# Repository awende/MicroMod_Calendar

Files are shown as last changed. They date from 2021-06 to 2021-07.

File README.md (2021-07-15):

# MicroMod Calendar

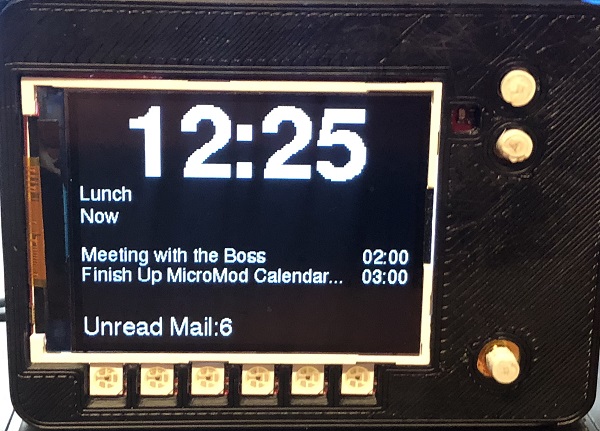
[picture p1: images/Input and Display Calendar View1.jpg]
MicroMod Input and Display Calendar Default View


The MicroMod Calendar uses the SparkFun Input and Display MicroMod Carrier board, paired with the SparkFun ESP32 MicroMod Processor board to show the current time, display next and upcoming meetings, and provide visual alerts using the on-board LEDs. The 5-way switch changes the backlight level, screen orientation, and a secondary view, which provides a little more space between your next meeting and future meetings.

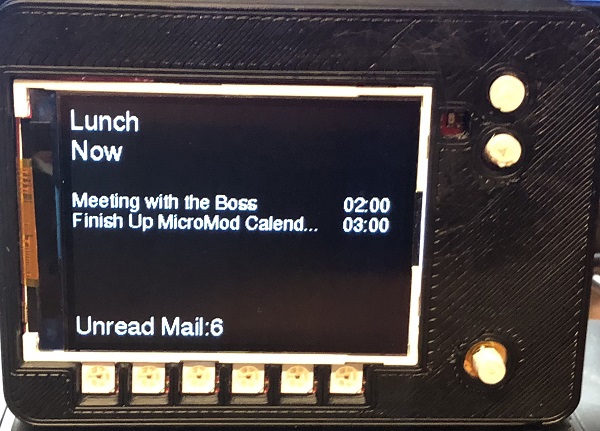
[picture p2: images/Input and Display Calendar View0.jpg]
MicroMod Input and Display Calendar Alternate View


To get this project working, there are two sets of code needed. The first is a script which is added to your Google account, and creates a file which pulls in the meetings from your calendar, and checks to see how many unread emails there are. The second runs on the ESP32, to connect to the Internet to read the data in, and get the current time which can automatically adjust for Dalight Savings based on the the timezone information provided.

Repository Contents
-------------------
* **/Case Files** - .stl files for the case, along with button caps
* **/Firmware** - Arduino code for the ESP32 Micromod, along with the script that needs to be connected to your Google account.

Hardware Used
-------------------
* [SparkFun ESP32 MicroMod Processor Board](https://www.sparkfun.com/products/16781)
* [SparkFun MicroMod Input and Display Carrier Board](https://www.sparkfun.com/products/16985)

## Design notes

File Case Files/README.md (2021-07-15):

This folder contains the 3D models used for the MicroMod Calendar case. The top of the case provides recesses for the switches' housing, and top mounted parts, along with cutouts for the USB-C connector, LCD, LEDs, and buttons. The bottom case has a cutout for the USB-C connector and standoff holes for 4-40 hardware. Hardware isn't needed though as the fit for the Input and Display board is nicely sandwiched between the top and bottom case to hold it in place.

With a little pressure, the 5-way switch cap is held on securely, but round actuators for the button switch caps were a bit tricky to fit correctly. In my prints the recess for the button switches were a bit too tight and I had to hold them with pliers to drill to the correct diameter. The button switch actuators are 0.080" in diamter, and a 0.076" drill provided a good snug fit.

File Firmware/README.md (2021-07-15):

# MicroMod Calendar Firmware

To display your calendar on the SparkFun Input and Display Carrier board, you will need the firmware for the ESP32, along with a script that will arregrate the data from your Google account to a single file. The ESP32 then reads the data and parses it to show on the display. Each peice of firmware goes into more deail below.

## Google Apps Script

There are a few items that the ESP32 needs to access from your Google account:

* Total number of unread emails in your Inbox
* Total number of meetings for the current day
* Name, start time, and end time of each meeting
* Total number of meetings for the next day
* Name, state time, and end time of your first meeting for the next day

In order of the ESP32 to read this information, we'll need to add the script from the CalendarEvents.gs file. To add the script, head over to https://script.google.com and click on new project.

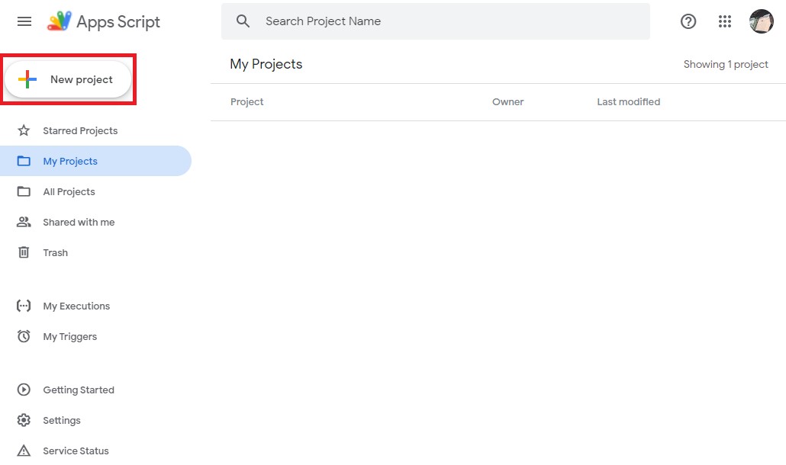
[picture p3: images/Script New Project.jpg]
New Project


From there, add a name for the project. I just called mine "CalendarEvents". Now we can add the code from CalendarEvents.gs file by pasting it into the script editor. Find the variable `_calendarName`, and inside the quotes, add the name of your calendar to add, e.g. 'Work', or your email address. We can test to make sure everything is working by pressing save and then pressing the run button.

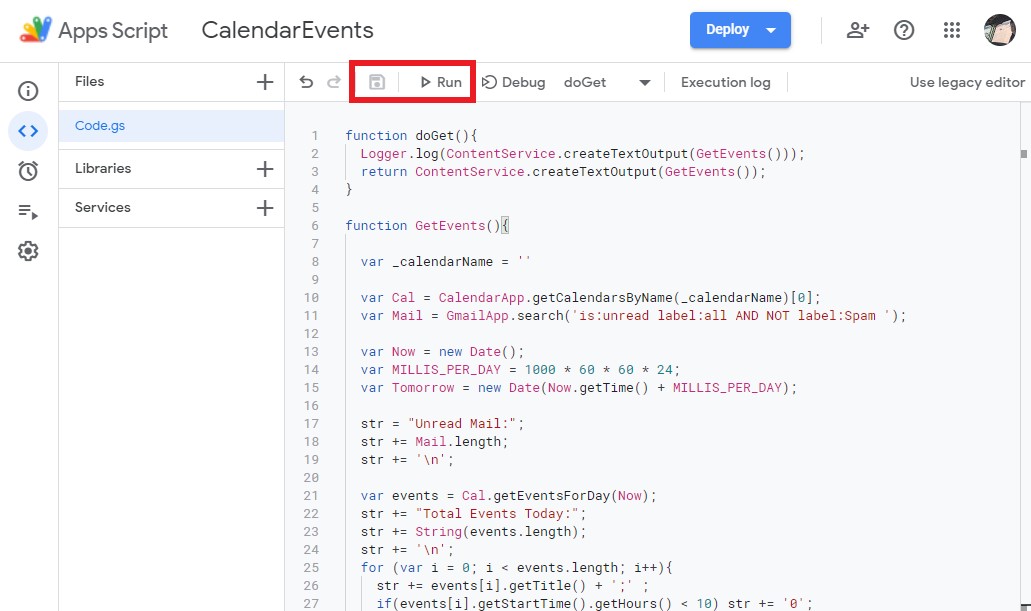
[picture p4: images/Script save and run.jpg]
Save and Run Icons


The first time you do this, a window will pop up saying "Authorizaton required". After allowing the script to access your Gmail and Calendar apps, the script will run and an execution log will pop up from the bottom of the screen which should show all of the information outlined above.

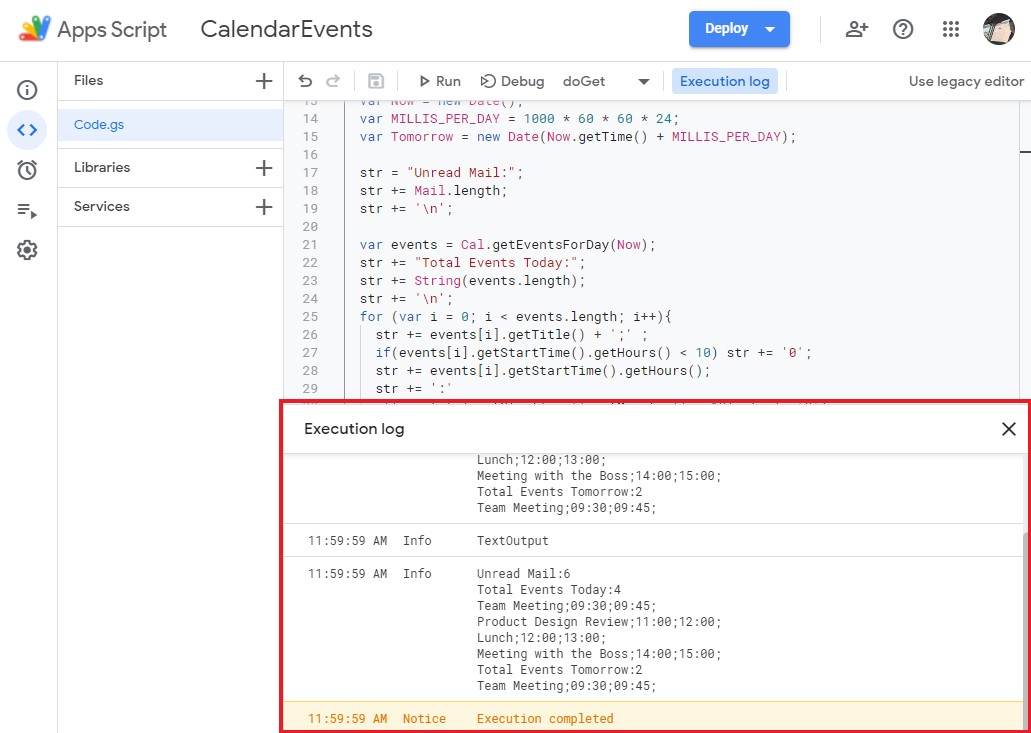
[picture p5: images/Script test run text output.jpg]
Script Test Run Text Output


By default, to get the number of unread emails, the script searches for `is:unread label:all AND NOT label:Spam`. If there are specific unread emails you would like to filter, you can modify the search operators outlined [here](https://support.google.com/mail/answer/7190?hl=en). Once the scipt is working as expected, we need to let the ESP32 get access to the data. To do that the script needs to be deployed by clicking on "Deploy" -> New deployment. 

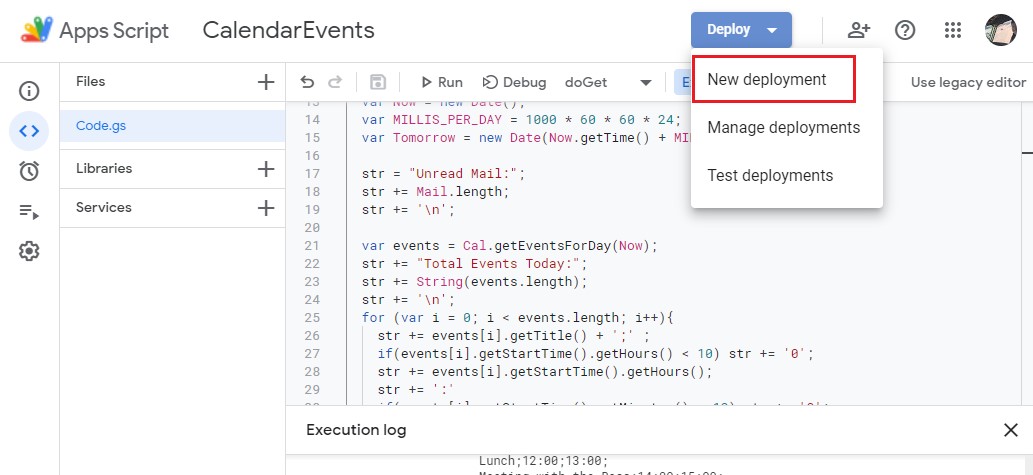
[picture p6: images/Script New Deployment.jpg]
New Deployment


Click on the gear icon and select Web app as your deployment type. You can provide a description if you want, but under web app, we want to make sure to have your email selected for "execute as", and for "Who has access", select anyone because the ESP32 won't be signing into Google. The last step is to click on deploy, which will generate the Deployment ID token that the ESP32 uses.

If you make any changes to the script after deploying, you will have to save the changes and either create a new deployment, which will create a new ID, or manage deployment and create a new version which will use the same ID.

## ESP32 Firmware

Before uploading code to the ESP32, there are a few things to check. The first is to make sure you have all of the libraries installed. Most come with the package install of the ESP32 core for Arduino, but the ones that need to be manually added are:

* [APA102.h from Pololu](https://github.com/pololu/apa102-arduino)
* [Timezone.h from Jack Christensen](https://github.com/JChristensen/Timezone)
* [TimeLib from Paul Stoffregen](https://github.com/PaulStoffregen/Time)
* [SparkFun MicroMod Button from SparkFun](https://github.com/sparkfun/SparkFun_MicroMod_Button_Arduino_Library)
* [GFX](https://github.com/adafruit/Adafruit-GFX-Library) and [ILI9341](https://github.com/adafruit/Adafruit_ILI9341) from Adafruit

Aside from the TimeLib library, each library can be found in Arduino's Library manager. For the TimeLib, head over to Paul's github page and download the library, and add the .zip to your library.

Once all of that is done, enter the network credentials for your WiFi network, and paste in the deployment ID of the script. To make sure you get the alerts on time, update the timezone information for your area. US Mountain Time Zone is there for a reference to help fill it in correctly. If your area doesn't do daylight savings you can just fill in standard time rule, and use that rule for both inputs for the timezone.

And that should be it, you can upload the code to your board. Once the board finishes uploading, it will reboot and try to connect to your Wi-Fi network to get the current time and get your calendar information. Every minute it will check the calendar to see if anything changed. It can take a little bit of time to get the information from your calendar, so to try and keep the user interface smooth, Core0 of the ESP32 will check for button presses from the switches, and update the diplay every minute, even if the other core is checking for any updates from the calendar.

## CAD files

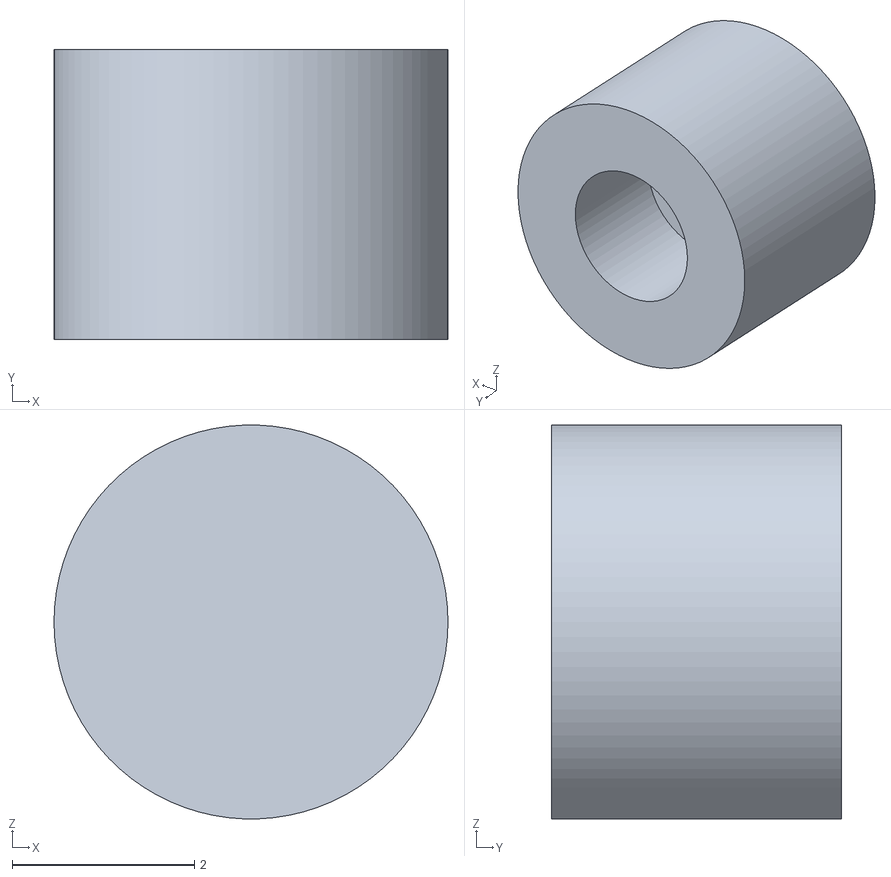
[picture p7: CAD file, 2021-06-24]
Case Files/Button Switch Cap.stl
4.32 x 3.17 x 4.31

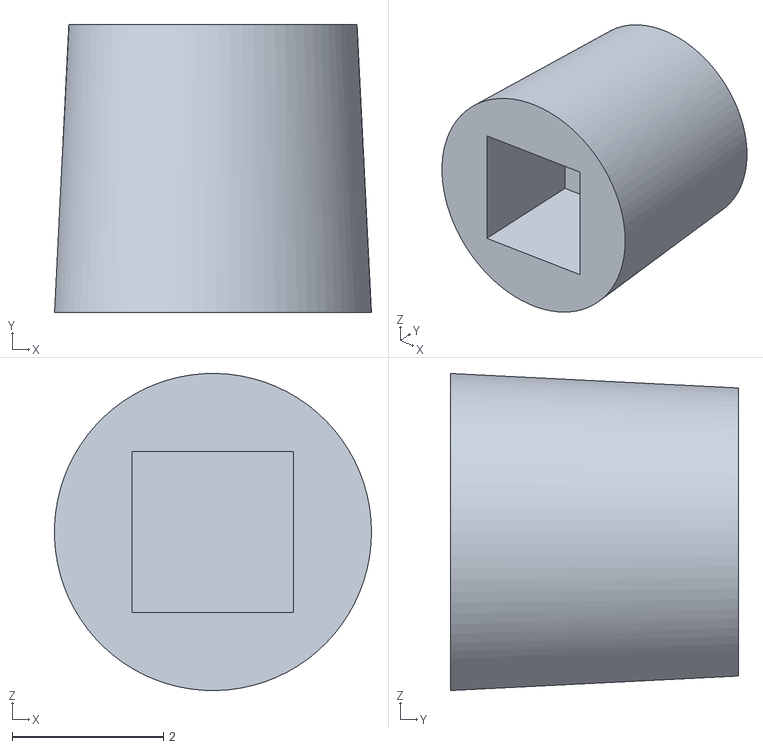
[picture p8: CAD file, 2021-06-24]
Case Files/5-way Switch Cap.stl
4.19 x 3.81 x 4.19

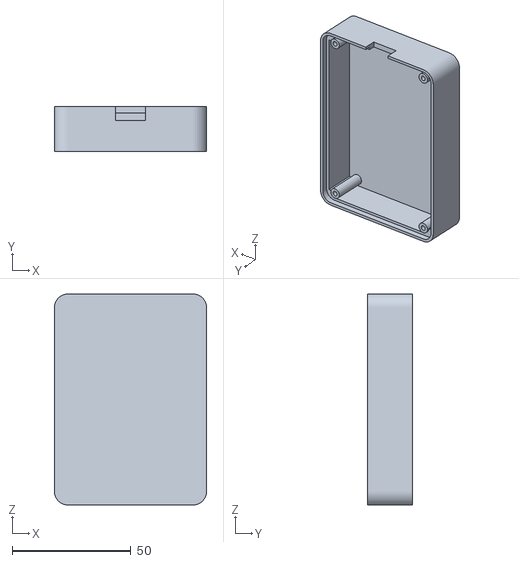
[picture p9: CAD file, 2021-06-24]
Case Files/MicroMod Input and Display Case Bottom.stl
64.1 x 19.0 x 88.9

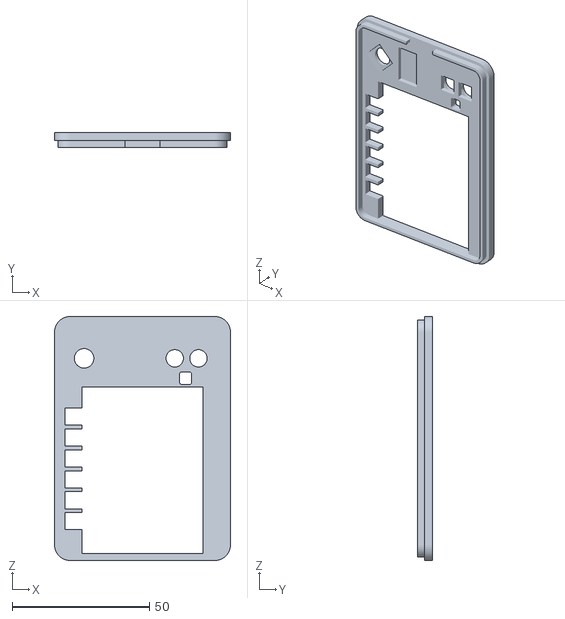
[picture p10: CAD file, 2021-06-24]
Case Files/MicroMod Input and Display Case Top.stl
64.1 x 5.59 x 88.9

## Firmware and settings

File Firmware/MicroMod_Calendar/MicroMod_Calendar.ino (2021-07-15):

/*
 * SparkFun MicroMod Input and Display Calendar
 * 
 * To use this code you will need to provide the SSID and password of the network to connect to,
 * along with the deployment ID for the Google Apps Script. 
 * 
 * After the ESP32 MicroMod Processor board connects to the Internet it will connect to an NTP server
 * and talks to a Google Apps Script to retreive:
 * - Total number of calendar events for the current day
 * - Name, start time, end time of those calendar events
 * - Number of events for the next day
 * - Name, start time, end time for the first calendar event of the next day
 * - Number of unread emails in the inbox
 * 
 * Depending on the display image, it will show the current time, next meeting along with how far
 * away that meeting is, up to 3 future meetins along with their start times, and how many unread
 * emails are in your inbox.
 * 
 * The 5-way switch on the on the Input and Display board can be used to change the display in the 
 * following ways:
 * - Left/Right cycles between showing or hiding the current time
 * - Up/Down changes between 10 backlight brightness levels
 * - Center rotates the display 180 degrees and swaps backlight controls
*/

#include <WiFi.h>
#include <WiFiUdp.h>
#include <WiFiClientSecure.h>
#include <EEPROM.h>
#include <SPI.h>
#include <Wire.h>

#include <APA102.h>                   //http://librarymanager/All#APA102 by Pololu
#include <Timezone.h>                 //http://librarymanager/All#Timezone by Jack Christensen, which depends on the TimeLib library from Paul Stoffregen https://github.com/PaulStoffregen/Time
#include <SparkFun_MicroMod_Button.h> //http://librarymanager/All#SparkFun_MicroMod_Button

#include <Adafruit_GFX.h>             //http://librarymanager/All#Adafruit_GFX
#include <Adafruit_ILI9341.h>         //http://librarymanager/All#Adafruit_ILI9341
#include <Fonts/FreeSans9pt7b.h>      //Front are provided in the GFX library
#include <Fonts/FreeSans12pt7b.h>
#include <Fonts/FreeSans18pt7b.h>
#include <Fonts/FreeSans24pt7b.h>
#include <Fonts/FreeSansBold24pt7b.h>

const char* ssid = "";
const char* pass = "";
String deploy_id = "";

//TimeChangeRule Structure: {Abbrev (5 Char max), Week (First, Second, Third, Fourth, or Last), DayOfWeek (1=Sun, 2=Mon, etc), Month, hour (0-23), offset (from UTC in minutes)}
// US Mountain Time Zone (Denver)
TimeChangeRule usMDT = {"MDT", Second, dowSunday, Mar, 2, -360}; //Daylight Savings Time rule
TimeChangeRule usMST = {"MST", First, dowSunday, Nov, 2, -420};  //Standard Time rule
Timezone usMT_DST(usMDT, usMST);

#define BACKLIGHT_PIN PWM0
#define TFT_CS_PIN D0
#define TFT_DC_PIN D1
#define LED_DATA_PIN G1
#define LED_CLOCK_PIN G0

WiFiClientSecure client;
char calendarServer[] = "script.google.com";

time_t utc;
time_t prevNow=0;

WiFiUDP Udp;                    //Initialize UDP library
unsigned int localPort = 8888;  // local port to listen for UDP packets

/* Array of ntp servers - I've had troubles in the past reliably connecting to time.gov
 * and using an array of servers seems to work better for me at least.
*/
const char ntpServerName[14][25] = {
  //Maryland
  "time-a-g.nist.gov",
  "time-b-g.nist.gov",
  "time-c-g.nist.gov",
  "time-d-g.nist.gov",
  //Fort Collins
  "time-a-wwv.nist.gov",
  "time-b-wwv.nist.gov",
  "time-c-wwv.nist.gov",
  "time-d-wwv.nist.gov",
  //Boulder
  "time-a-b.nist.gov",
  "time-b-b.nist.gov",
  "time-c-b.nist.gov",
  "time-d-b.nist.gov",
  //University of Colorado, Boulder
  "utcnist.colorado.edu",
  "utcnist2.colorado.edu"
};

const int NTP_PACKET_SIZE = 48; // NTP time is in the first 48 bytes of message
byte packetBuffer[NTP_PACKET_SIZE]; //buffer to hold incoming & outgoing packets

APA102<LED_DATA_PIN, LED_CLOCK_PIN> ledStrip;
const uint16_t ledCount = 6;
rgb_color colors[ledCount];

MicroModButton button;
Adafruit_ILI9341 tft = Adafruit_ILI9341(TFT_CS_PIN,TFT_DC_PIN);

//Data to get from Google
int totalEventsToday = 0;
String calEntToday[10][3];  //calEntToday[Event #][Name,Start Time, End Time]
int totalEventsTomorrow = 0;
String calEntTomorrow[3];   //calEntTomorrow[Name,Start Time, End Time]
int unreadMail = 0;

bool orientation = 0; //0-USB on left side, 1-USB on right side
bool displayType = 1; //0-Don't show the time, 1-Do show the time
int backlight = 9;  //Backlight brightness level (0-9)
double prevTime = 0;

/* Pin button presses and updating display to Core0
 * This allows the display to change without having to wait for responses from Google if
 * the ESP32 is trying to get the latest calendar and mail data.
*/
void Task1code( void * pvParameters )
{
  while(true)
  {
    vTaskDelay(10);

    //Check to see if a button has been pressed
    if(button.getPressed() != 0)
    {
      uint8_t pressed = button.getPressed(); //Read which button has been pressed
      
      if(pressed & 0x04 || pressed & 0x08)
      {
        displayType = !displayType;
        
        EEPROM.write(1,displayType);
        EEPROM.commit();
        
        tft.fillScreen(ILI9341_BLACK);
        updateDisplay(displayType);
      }
      else if(pressed & 0x20) //Change Backlight
      {
        byte pwmVal = 0;

        if(orientation) //orientation = 1
        {
          backlight++;
          if(backlight > 9) backlight = 9;
        }
        else //orientation = 0
        {
          backlight--;
          if(backlight < 0) backlight = 0;
        }

        EEPROM.write(0,backlight);
        EEPROM.commit();
        
        pwmVal = map(backlight,0,9,255,0);
        ledcWrite(1,pwmVal);
      }
      else if(pressed & 0x10) //Change Backlight
      {
        byte pwmVal = 0;
        
        if(orientation) //orientation = 1
        {
          backlight--;
          if(backlight < 0) backlight = 0;
        }
        else //orientation = 0
        {
          backlight++;
          if(backlight > 9) backlight = 9;
        }

        EEPROM.write(0,backlight);
        EEPROM.commit();
        
        pwmVal = map(backlight,0,9,255,0);
        ledcWrite(1,pwmVal);
      }
      else if(pressed & 0x40)
      {
        orientation = !orientation;
        EEPROM.write(2,orientation);
        EEPROM.commit();

        tft.setRotation(orientation*2 + 1); //Sets the display in landscape (1 or 3)
        updateDisplay(displayType);
      }
      
      while(button.getPressed() != 0) { vTaskDelay(10); }
    }

    //Update Display every minute
    if((now()/60 != prevNow/60) && (WiFi.status() == WL_CONNECTED))  
    {
      Serial.println(currentTime());
      updateDisplay(displayType);
  
      time_t t = getLocal();
      int currentTime = hour(t)*60 + minute(t);
      
      for(byte i=0; i<totalEventsToday; i++)
      {
        int startTime = calEntToday[i][1].substring(0,2).toInt()*60 + calEntToday[i][1].substring(3).toInt();
        if(((startTime - currentTime) <= 10) && (startTime >= currentTime))
        {
          if((startTime - currentTime) == 10) displayAlert(0);
          else if((startTime - currentTime) == 5) displayAlert(1);
          else if((startTime - currentTime) == 0) displayAlert(2);
          break;
        }
      }
    }
  }
}

void setup()
{
  //Initialize Communication Buses and EEPROM
  Serial.begin(115200);
  Wire.begin();
  EEPROM.begin(3);

  ledcAttachPin(BACKLIGHT_PIN,1);
  ledcSetup(1,10000,8);
  
  //Read backlight memory value
  backlight = EEPROM.read(0);
  if(backlight > 9) backlight = 9;

  //Set backlight
  ledcWrite(1,map(backlight,0,9,255,0));

  //Read display view memory value
  displayType = EEPROM.read(1);

  //Read orientation of display
  orientation = EEPROM.read(2);
  
  Serial.println("\nMICROMOD GOOGLE CALENDAR Display");

  //Initialize buttons
  button.begin();

  //Initialize display
  tft.begin();
  tft.invertDisplay(true);
  tft.setRotation(orientation*2 + 1); //Sets the display in landscape (1 or 3)
  tft.setTextColor(ILI9341_WHITE);
  tft.fillScreen(ILI9341_BLACK);

  // Boot Screen
  tft.setFont(&FreeSans18pt7b);
  tft.setCursor(8,60);
  tft.print("MicroMod Calendar");

  //Connect to WiFi
  tft.setFont(&FreeSans12pt7b);
  tft.setCursor(0,160);
  tft.print("Status: Connecting to WiFi");
  connectToWifi();

  //Get calendar from Google
  tft.fillRect(0,140,320,30,ILI9341_BLACK);
  tft.setCursor(0,160);
  tft.print("Status: Fetching Calendar");
  tft.print("\n(this can take a little bit)");
  fetchData();

  //Show main display
  updateDisplay(displayType);

  //function to get the current time and sync up every x number of seconds
  setSyncProvider(getNtpTime);
  setSyncInterval(300);
  
  Serial.println(currentTime());
  
  //Pin task function to Core0
  TaskHandle_t Task1;
  xTaskCreatePinnedToCore(
                    Task1code,   /* Function to implement the task */
                    "Task1", /* Name of the task */
                    10000,      /* Stack size in words */
                    NULL,       /* Task input parameter */
                    1,          /* Priority of the task */
                    &Task1,       /* Task handle. */
                    0);  /* Core where the task should run */
  Serial.println("Task created");

  prevTime = millis();
}

void loop() 
{
  //Check for calendar/mail update every minute (60000ms)
  if((millis()-prevTime > 60000) && (WiFi.status() == WL_CONNECTED))
  {
    fetchData();
    prevTime = millis();
  }
}

// Main function that controls what is shown on the display
void updateDisplay(uint8_t display)
{  
  time_t t = getLocal();
  prevNow = now();

  int currentTime = hour(t)*60 + minute(t);
  
  if(displayType == 0)
  {
    tft.fillScreen(ILI9341_BLACK);
    tft.setFont(&FreeSans12pt7b);
    tft.setTextSize(1);
  
    //Print first event of tomorrow
    //This will be over written if there is a meeting before tomorrow
    tft.setCursor(0,60);
    tft.print(totalEventsTomorrow);
    if(totalEventsTomorrow == 1) { tft.print(" meeting tomorrow."); }
    else { tft.print(" meetings tomorrow."); }

    if(totalEventsTomorrow != 0)
    {
      tft.setCursor(0,100);
      tft.print("Up next tomorrow:");
      tft.setCursor(0,130);
      tft.print(calEntTomorrow[0].substring(0,27));
      tft.setCursor(260,130);
      int eventStart = calEntTomorrow[1].substring(0,2).toInt();
      if(eventStart > 12) eventStart -= 12; //Convert from 24hr to 12hr format
      tft.print(eventStart/10);
      tft.print(eventStart%10);
      tft.print(':');
      tft.print(calEntTomorrow[1].substring(3));
    }

    for(byte i=0; i<totalEventsToday; i++)
    {
      int eventStart = calEntToday[i][1].substring(0,2).toInt()*60 + calEntToday[i][1].substring(3).toInt();
      int eventEnd = calEntToday[i][2].substring(0,2).toInt()*60 + calEntToday[i][2].substring(3).toInt();
      
      if(currentTime < (eventEnd-5)) //Give 5min buffer for back to back meetings
      {
        tft.fillScreen(ILI9341_BLACK);
        tft.setFont(&FreeSans12pt7b);
        tft.setTextSize(1);

        //Print next event
        tft.setCursor(0,25);
        tft.print(calEntToday[i][0].substring(0,27));
        if(calEntToday[i][0].length() > 27) tft.print("...");
        
        int timeLeft = eventStart - currentTime;

        if(timeLeft > 0)
        {
          tft.print("\nIn ");
          if(timeLeft > 60)
          {
            tft.print(timeLeft/60);
            tft.print("hr ");
          }
          tft.print(timeLeft%60);
          tft.print("min");
        }
        else { tft.print("\nNow"); }
        
        tft.setFont(&FreeSans9pt7b);
        tft.setTextSize(1);

        //Print up to 3 upcoming events after the next meeting
        for(byte j=0;j<3;j++)
        {
          if( (i+j+1)<totalEventsToday )
          {
            int eventStart = calEntToday[i+j+1][1].substring(0,2).toInt();
            if(eventStart > 12) eventStart -= 12;
            tft.setCursor(0,j*20 + 100);
            tft.print(calEntToday[i+j+1][0].substring(0,25));
            if(calEntToday[i+j+1][0].length() > 25) tft.print("...");
            tft.setCursor(260,j*20 + 100);
            tft.print(eventStart/10);
            tft.print(eventStart%10);
            tft.print(':');
            tft.print(calEntToday[i+j+1][1].substring(3));
          }
        }
        break;
      }
    }
    
    //Print unread mail
    tft.setFont(&FreeSans12pt7b);
    tft.setTextSize(1);
    tft.setCursor(0,230);
    tft.print("Unread Mail:");
    tft.print(unreadMail);
  }
  else
  {
    tft.fillScreen(ILI9341_BLACK);
    tft.setFont(&FreeSansBold24pt7b);
    tft.setTextSize(2);

    //Print current time
    tft.setCursor(40,70);
    tft.print(hourFormat12(t)/10);
    tft.print(hourFormat12(t)%10);
    tft.print(':');
    tft.print(minute(t)/10);
    tft.print(minute(t)%10);
    
    tft.setFont(&FreeSans9pt7b);
    tft.setTextSize(1);

    //Print tomorrow's schedule
    //This will be over written if there is a meeting before tomorrow
    tft.setCursor(0,120);
    tft.print(totalEventsTomorrow);
    if(totalEventsTomorrow == 1) { tft.print(" meeting tomorrow."); }
    else { tft.print(" meetings tomorrow."); }

    if(totalEventsTomorrow != 0)
    {
      tft.setCursor(0,160);
      tft.print("Up next tomorrow:");
      tft.setCursor(0,185);
      tft.print(calEntTomorrow[0].substring(0,35));
      tft.setCursor(270,185);
      int eventStart = calEntTomorrow[1].substring(0,2).toInt();
      if(eventStart > 12) eventStart -= 12;
      tft.print(eventStart/10);
      tft.print(eventStart%10);
      tft.print(':');
      tft.print(calEntTomorrow[1].substring(3));
    }

    for(byte i=0; i<totalEventsToday; i++)
    {
      int eventStart = calEntToday[i][1].substring(0,2).toInt()*60 + calEntToday[i][1].substring(3).toInt();
      int eventEnd = calEntToday[i][2].substring(0,2).toInt()*60 + calEntToday[i][2].substring(3).toInt();
      
      if(currentTime < (eventEnd-5)) //Give 5min buffer for back to back meetings
      {
        tft.fillRect(0,80,320,160,ILI9341_BLACK);

        //Print next event
        tft.setCursor(0,95);
        tft.print(calEntToday[i][0].substring(0,35));
        if(calEntToday[i][0].length() > 30) tft.print("...");
        tft.println();
        
        int timeLeft = eventStart - currentTime;
        if(timeLeft > 0)
        {
          tft.print("In ");
          if(timeLeft >= 60)
          {
            tft.print(timeLeft/60);
            tft.print("hr ");
          }
          tft.print(timeLeft%60);
          tft.print("min");
        }
        else { tft.print("Now"); }
        
        //Print up to 3 upcoming events after the next meeting
        for(byte j=0;j<3;j++)
        {
          if( (i+j+1)<totalEventsToday )
          {
            int eventStart = calEntToday[i+j+1][1].substring(0,2).toInt();
            if(eventStart > 12) eventStart -= 12;
            tft.setCursor(0,j*20 + 155);
            tft.print(calEntToday[i+j+1][0].substring(0,27));
            if(calEntToday[i+j+1][0].length() > 27) tft.print("...");
            tft.setCursor(270,j*20 + 155);
            tft.print(eventStart/10);
            tft.print(eventStart%10);
            tft.print(':');
            tft.print(calEntToday[i+j+1][1].substring(3));
          }
        }
        break;
      }
    }
    
    //Print unread mail
    tft.setFont(&FreeSans12pt7b);
    tft.setTextSize(1);
    tft.setCursor(0,230);
    tft.print("Unread Mail:");
    tft.print(unreadMail);
  }
}

// Connects to the WiFi Station based on the provided SSID and password provided
void connectToWifi()
{
  Serial.print("\nConnecting to wifi: ");
  Serial.println(ssid);

  WiFi.begin(ssid, pass);
  uint32_t startTime = millis();
  bool tryingAlt = 0;
  while (WiFi.status() != WL_CONNECTED)
  {
    delay(500);
    Serial.print(".");
  }
  Serial.print("\nWiFi connected ");
  Serial.print("IP address: ");
  Serial.println(WiFi.localIP());

  Serial.println("Starting UDP");
  Udp.begin(localPort);
}

//Connects to script.google.com to get calendar/mail info
bool fetchData()
{  
  // Getting calendar from your published google script
  String calendarRequest = "https://script.google.com/macros/s/"+ deploy_id +"/exec";
  String outputStr = ""; //HTML response from calendarRequest
  String strData = "";   //Used as a buffer to store smaller bits of outputStr
  int indexFrom = 0;
  int indexTo   = 0;  
  int attempts = 0;

  //Sometimes the request doesn't return any data, so we'll retry a few times
  while(outputStr.indexOf("Total Events Today:") == -1 && attempts < 10)
  {
    // If redirected - then follow redirect - google always redirect to a temporary URL by default.
    if(outputStr.indexOf("Location:") > 0 )
    {
      int indexFrom = outputStr.indexOf("Location:") + 10;
      int indexTo = outputStr.indexOf("\n", indexFrom);
      String newUrl = outputStr.substring(indexFrom, indexTo);

      getRequest(calendarServer, newUrl);
      outputStr = client.readString();
    }
    else
    {
      getRequest(calendarServer, calendarRequest);
      outputStr = client.readString();
    }
    attempts++;
  }

  if(outputStr.indexOf("Total Events Today:") > 0)
  {
    Serial.println("Received data");

    //Get the number of unread messages in Email
    indexFrom = outputStr.indexOf("Unread Mail:");
    strData = outputStr.substring(indexFrom);
    indexTo = strData.indexOf('\n');
    unreadMail = strData.substring(12,indexTo).toInt();
  
    //Get the number of calendar events for tomorrow
    indexFrom = outputStr.indexOf("Total Events Tomorrow:");
    strData = outputStr.substring(indexFrom);
    indexTo = strData.indexOf('\n');
    totalEventsTomorrow = strData.substring(22,indexTo).toInt();
  
    //Get the name of the first event tomorrow
    indexFrom = strData.indexOf("\n");
    indexTo = strData.indexOf(";");
    
    for(byte i=0; i<3; i++)
    {
      calEntTomorrow[i] = strData.substring(indexFrom+1,indexTo);
     
      indexFrom = strData.indexOf(";",indexTo);
      indexTo = strData.indexOf(";",indexFrom+1);
    }
  
    //Get the number of events for today
    indexFrom = outputStr.indexOf("Total Events Today:");
    strData = outputStr.substring(indexFrom);
    indexTo = strData.indexOf('\n');
    totalEventsToday = strData.substring(19,indexTo).toInt();
  
    //Get the names of the events for today
    indexFrom = 0;
    indexTo = 1;
  
    for(byte i=0; i<totalEventsToday; i++)
    {
      indexFrom = strData.indexOf("\n",indexTo-1);
      indexTo = strData.indexOf(";",indexFrom);
      for(byte j=0; j<3; j++)
      {
        calEntToday[i][j] = strData.substring(indexFrom+1,indexTo);
        if(j != 2)
        {
          indexFrom = strData.indexOf(";",indexTo);
          indexTo = strData.indexOf(";",indexFrom+1);
        }
      }
    }
  }
  else { Serial.println("Unable to get data"); }

  client.stop();  
  return true;
}
 
// Generic code for getting requests
bool getRequest(char *urlServer, String urlRequest)
{
  client.stop(); // close connection before sending a new request
 
  if (client.connect(urlServer, 443)) //If the connection succeeds
  {
    Serial.println("connecting...");
    // send the HTTP PUT request:
    client.println("GET " + urlRequest); // " HTTP/1.1"
    Serial.println("GET " + urlRequest);
    client.println("User-Agent: ESP32 MicroMod/1.1");
    client.println();
    
    unsigned long timeout = millis();
    while (client.available() == 0) 
    {      
      if (millis() - timeout > 5000) 
      {
        Serial.println(">>> Client Timeout !");
        client.stop();
        Serial.println("Connection timeout");  
        return false;
      }
    }
    Serial.print("Response Time:");
    Serial.println(millis()-timeout);
  } 
  else { Serial.println(F("Calendar connection did not succeed")); }  
  return true;
}

// Controls the APA102 LEDs based on the alert level
// 0-Green (10min) 1-Yellow (5min) 2-Red (0min)
void displayAlert(byte level)
{
  rgb_color alert_color;
  byte brightness = 5;
  
  if(level == 0) alert_color = rgb_color(0,170,0);        //Green
  else if(level == 1) alert_color = rgb_color(255,170,0); //Yellow
  else if(level == 2) alert_color = rgb_color(255,0,0);   //Red
  
  for(uint16_t i = 0; i < ledCount; i++)
  {
    colors[i] = alert_color;
  }
  ledStrip.write(colors, ledCount, brightness);
  delay(100);
  for(uint16_t i = 0; i < ledCount; i++)
  {
    colors[i] = rgb_color(0,0,0);
  }
  ledStrip.write(colors, ledCount, brightness);
  delay(100);
  for(uint16_t i = 0; i < ledCount; i++)
  {
    colors[i] = alert_color;
  }
  ledStrip.write(colors, ledCount, brightness);
  delay(100);
  for(uint16_t i = 0; i < ledCount; i++)
  {
    colors[i] = rgb_color(0,0,0);
  }
  ledStrip.write(colors, ledCount, brightness);
  delay(500);
  for(uint16_t i = 0; i < ledCount; i++)
  {
    colors[i] = alert_color;
  }
  ledStrip.write(colors, ledCount, brightness);
  delay(100);
  for(uint16_t i = 0; i < ledCount; i++)
  {
    colors[i] = rgb_color(0,0,0);
  }
  ledStrip.write(colors, ledCount, brightness);
  delay(100);
  for(uint16_t i = 0; i < ledCount; i++)
  {
    colors[i] = alert_color;
  }
  ledStrip.write(colors, ledCount, brightness);
  delay(100);
  for(uint16_t i = 0; i < ledCount; i++)
  {
    colors[i] = rgb_color(0,0,0);
  }
  ledStrip.write(colors, ledCount, brightness);
}
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

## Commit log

2021-06-24 intial commit
    [5-way Switch Cap.stl, Button Switch Cap.stl, MicroMod Input and Display Case Bottom.stl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]
2021-06-28 Added Case Files Readme
2021-07-15 Minor changes
    Fixed grammar for future meetings
    [MicroMod_Calendar.ino]
